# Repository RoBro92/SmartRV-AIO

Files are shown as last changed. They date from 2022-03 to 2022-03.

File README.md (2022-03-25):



# SmartRV AIO
**A ESP32 based smart home control board for a Camper/RV**

All feature requests are tracked in the GitHub issue tracker. 
[Feature Requests](https://github.com/RoBro92/feature-requests/issues)

This AIO board is planned to be able to work standalone or as part of a connected smart home network within a camper or RV. It will be designed based on suggestions from the community. As technology advances many are looking to automate tasks in day to day life, your recreational vehicle should be no different. Many existing monitoring systems are generally either very dated, or not very smart. This board will facilitate an all in one monitoring and control hub. 

The module has been kept as compact as possible and allows for a direct connection to 12v or 24v vehicle systems. 

**If you want to support the development you can purchase this board as a DIY kit or assembled from my Ko-Fi Shop [SmartRV Shop](https://ko-fi.com/smartrv/shop)**

## **I have developed two seperate versions of this module**

[AIO1 is THT and is suitable for at home soldering](#aio1)

[AIO2 is SMD and is designed to be assembled by a PCB manufacturer](#aio2)

###AIO1

# **THT Version 0.1**
This is the pre production initial design files with planned features and initial designs.

# **Features**
- [x] - ESP32 Microcontroller
- [x] - Individually controlled relays
- [x] - Input buttons 
- [x] - Tank temperature inputs
- [x] - Tank level inputs
- [x] - Auxilliary temperature & humidity input
- [x] - Spotlights/LED control & dimming
- [x] - RJ45 Output to Nextion Display
- [x] - Relay 1&2 are 12v direct supply for low current device 

# **Upcoming Changes**

- [ ] - RS485 serial connection
- [ ] - Bluetooth App
- [ ] - Bluetooth connection to external modules(such as Water tank module)
- [ ] - House battery voltage
- [ ] - Main battery voltage
- [ ] - On board programming
- [ ] - MQTT integration
- [ ] - Diesel heater control 

# **Images**

<table>
  <tr>
    <td>Schematic</td>
     <td>PCB Layout</td>
  </tr>
  <tr>
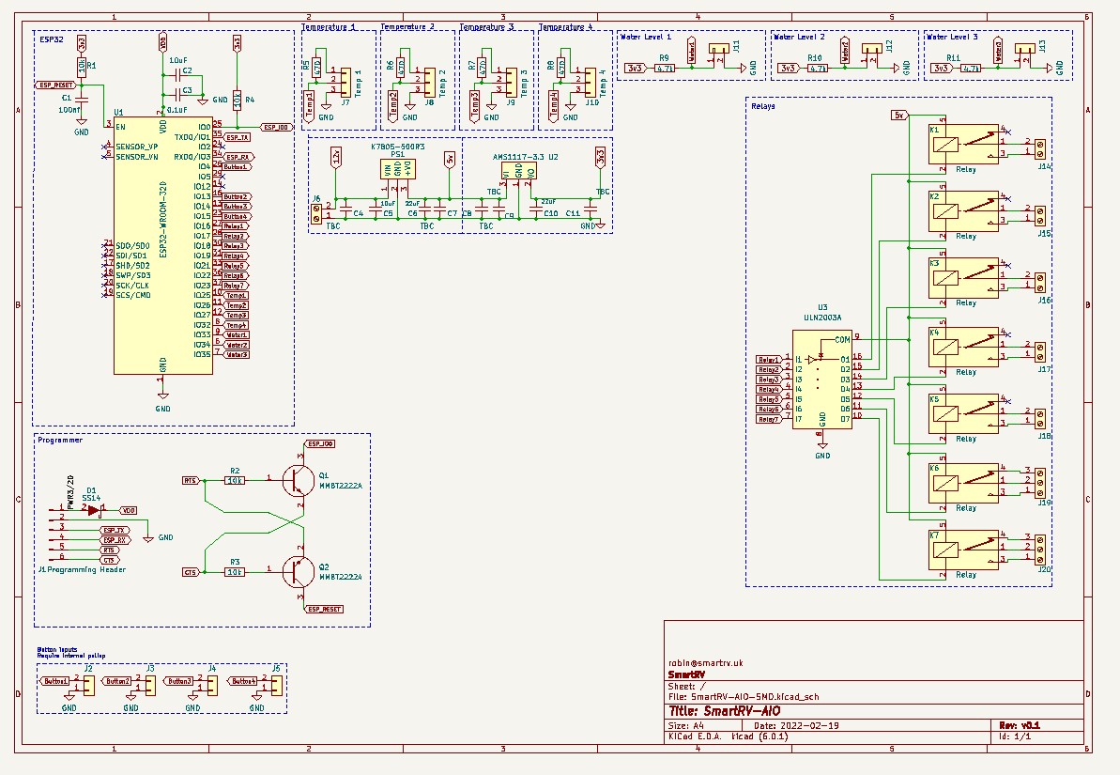
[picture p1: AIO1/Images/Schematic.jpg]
    <td></td>
    <td></td>
  </tr>
 </table>

# **WARNING**
This board does not have any fuse protection as such this must be provided externally.

###AIO2

# **SMD Version 0.1**
This is the pre production SMD initial design files with planned features and initial designs.

# **Features**
- [x] - ESP32 Microcontroller
- [x] - Individually controlled relays
- [x] - Input buttons 
- [x] - Tank temperature inputs
- [x] - Tank level inputs
- [x] - Auxilliary temperature & humidity input

# **Upcoming Changes**

- [ ] - RS485 serial connection
- [ ] - Bluetooth App
- [ ] - Bluetooth connection to external modules(such as Water tank module)
- [ ] - House battery voltage
- [ ] - Main battery voltage
- [ ] - On board programming
- [ ] - MQTT integration
- [ ] - Diesel heater control 
- [ ] - RJ45 Output to Nextion Display
- [ ] - Spotlights/LED control & dimming
- [ ] - Relay 1&2 are 12v direct supply for low current device 

# **Images**

<table>
  <tr>
    <td>Schematic</td>
     <td>PCB Layout</td>
  </tr>
  <tr>
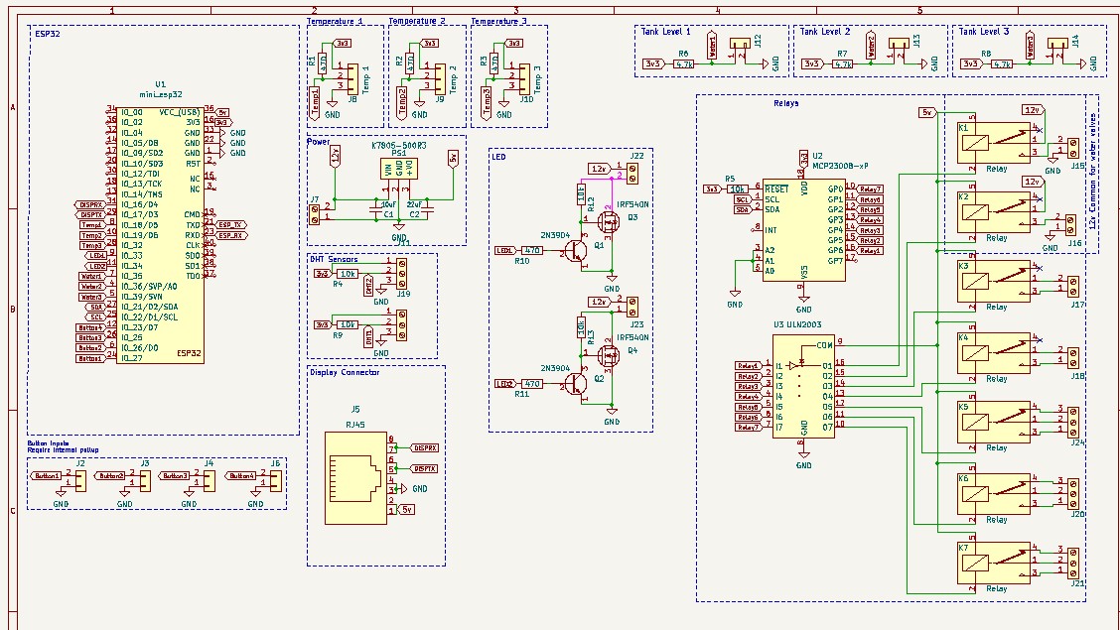
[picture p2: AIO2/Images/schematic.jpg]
    <td></td>
    <td></td>
  </tr>
 </table>

# **WARNING**
This board does not have any fuse protection as such this must be provided externally.

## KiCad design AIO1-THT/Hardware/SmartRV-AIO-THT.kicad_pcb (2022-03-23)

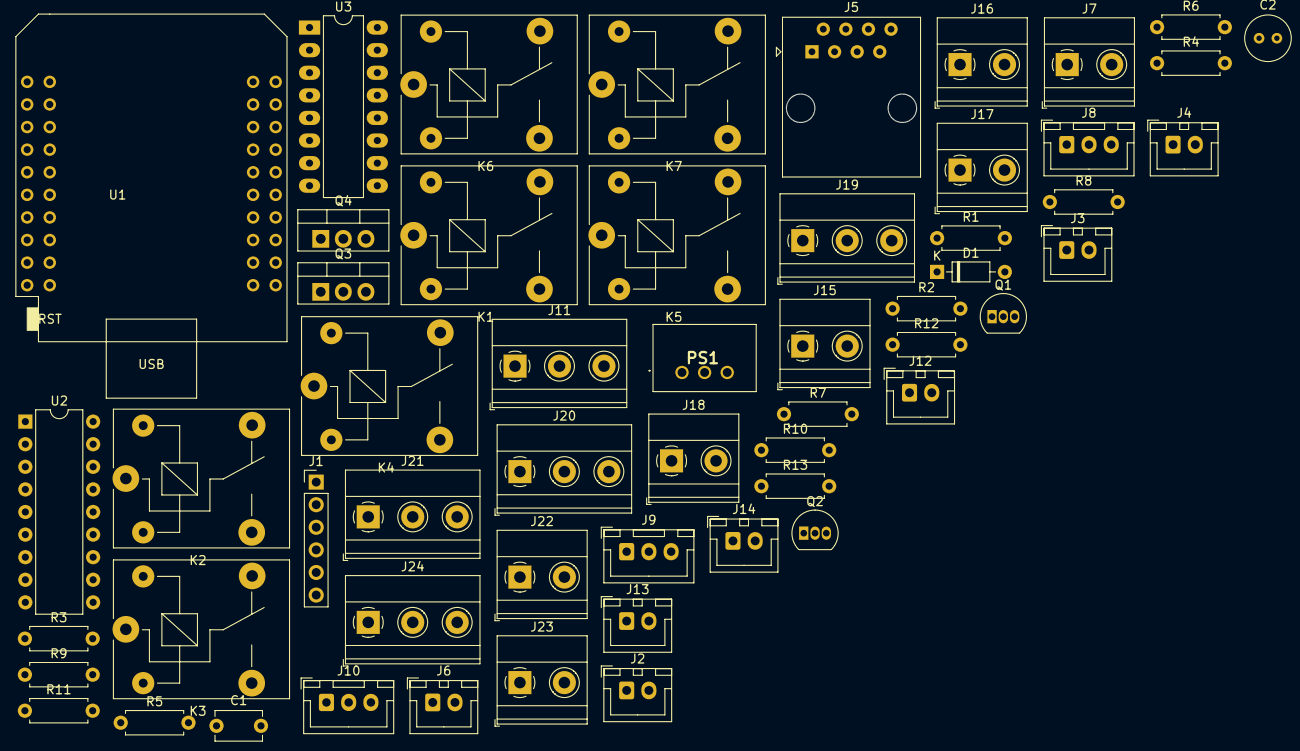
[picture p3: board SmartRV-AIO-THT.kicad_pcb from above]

Board: 2 copper layers, 55 parts (0 on the bottom side), 57 nets, no tracks yet.

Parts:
C1: 10uF; C_Disc_D5.1mm_W3.2mm_P5.00mm
C2: 22uF; C_Radial_D5.0mm_H5.0mm_P2.00mm
D1: 1N4148; D_DO-35_SOD27_P7.62mm_Horizontal
J1: Programming Header; PinHeader_1x06_P2.54mm_Vertical
J2: Button1; JST_XH_B2B-XH-A_1x02_P2.50mm_Vertical
J3: Button2; JST_XH_B2B-XH-A_1x02_P2.50mm_Vertical
J4: Button3; JST_XH_B2B-XH-A_1x02_P2.50mm_Vertical
J5: RJ45; RJ45_Amphenol_54602-x08_Horizontal
J6: Button4; JST_XH_B2B-XH-A_1x02_P2.50mm_Vertical
J7, J15, J16, J17, J18, J22, J23: Screw_Terminal_01x02; TerminalBlock_Phoenix_MKDS-1,5-2_1x02_P5.00mm_Horizontal
J8: Temp 1; JST_XH_B3B-XH-A_1x03_P2.50mm_Vertical
J9: Temp 2; JST_XH_B3B-XH-A_1x03_P2.50mm_Vertical
J10: Temp 3; JST_XH_B3B-XH-A_1x03_P2.50mm_Vertical
J11, J19, J20, J21, J24: Screw_Terminal_01x03; TerminalBlock_Phoenix_MKDS-1,5-3_1x03_P5.00mm_Horizontal
J12, J13, J14: Water Level Sensor; JST_XH_B2B-XH-A_1x02_P2.50mm_Vertical
K1, K2, K3, K4, K5, K6, K7: Relay; Relay_SPDT_SANYOU_SRD_Series_Form_C
PS1: K7805-500R3; K7805500R3
Q1, Q2: 2N3904; TO-92_Inline
Q3, Q4: IRF540N; TO-220-3_Vertical
R1, R2, R3: 470; R_Axial_DIN0207_L6.3mm_D2.5mm_P7.62mm_Horizontal
R4, R5, R9, R10, R11, R12, R13: 10k; R_Axial_DIN0207_L6.3mm_D2.5mm_P7.62mm_Horizontal
R6, R7, R8: 4.7k; R_Axial_DIN0207_L6.3mm_D2.5mm_P7.62mm_Horizontal
U1: mini_esp32; ESP32_mini
U2: MCP23008-xP; DIP-18_W7.62mm
U3: ULN2003; DIP-16_W7.62mm_LongPads

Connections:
3v3: J8.1, J9.1, J10.1, J11.1, J19.1, R1.1, R2.1, R3.1, R4.1, R5.1, R6.1, R7.1, R8.1, R9.1, U1.16 (3V3), U2.18 (VDD)
5v: C2.1, J5.1, J5.2, K1.5, K2.5, K3.5, K4.5, K5.5, K6.5, K7.5, PS1.3 (+VO), U1.35 (VCC_(USB)), U3.9 (COM)
12v: C1.1, J7.2, J22.1, J23.2, PS1.1 (VIN)
/PWR3/20: D1.2 (A), J1.1
DHT1: J19.2, R9.2
DHT2: J11.2, R4.2
DISPRX: J5.7, J5.8, U1.31 (IO_16/D4)
DISPTX: J5.5, J5.6, U1.29 (IO_17/D3)
ESP_RX: J1.4, U1.23 (RXD)
ESP_TX: J1.3, U1.21 (TXD)
GND: C1.2, C2.2, J1.2, J2.1, J3.1, J4.1, J5.3, J5.4, J6.1, J7.1, J8.3, J9.3, J10.3, J11.3, J12.2, J13.2, J14.2, J19.3, PS1.2 (GND), Q1.1 (E), Q2.1 (E), Q3.3 (S), Q4.3 (S), U1.1 (GND), U1.22 (GND), U1.33 (GND), U2.3 (A2), U2.4 (A1), U2.5 (A0), U2.9 (VSS), U3.8 (GND)
unnamed: J15.1, K1.3
unnamed: J15.2, K1.1
unnamed: J16.1, K2.3
unnamed: J16.2, K2.1
unnamed: J17.1, K3.3
unnamed: J17.2, K3.1
unnamed: J18.1, K4.3
unnamed: J18.2, K4.1
unnamed: J20.1, K6.3
unnamed: J20.2, K6.1
unnamed: J20.3, K6.4
unnamed: J21.1, K7.3
unnamed: J21.2, K7.1
unnamed: J21.3, K7.4
unnamed: K1.2, U3.16 (O1)
unnamed: K2.2, U3.15 (O2)
unnamed: K3.2, U3.14 (O3)
unnamed: K4.2, U3.13 (O4)
unnamed: J24.2, K5.1
unnamed: K5.2, U3.12 (O5)
unnamed: J24.1, K5.3
unnamed: J24.3, K5.4
unnamed: K6.2, U3.11 (O6)
unnamed: K7.2, U3.10 (O7)
unnamed: Q1.2 (B), R10.2
unnamed: Q1.3 (C), Q3.1 (G), R12.1
unnamed: Q2.2 (B), R11.2
unnamed: Q2.3 (C), Q4.1 (G), R13.1
unnamed: J22.2, Q3.2 (D), R12.2
unnamed: J23.1, Q4.2 (D), R13.2
unnamed: R5.2, U2.6 (~RESET)
Relay1: U2.16 (GP6), U3.1 (I1)
Relay2: U2.15 (GP5), U3.2 (I2)
Relay3: U2.14 (GP4), U3.3 (I3)
Relay4: U2.13 (GP3), U3.4 (I4)
Relay5: U2.12 (GP2), U3.5 (I5)
Relay6: U2.11 (GP1), U3.6 (I6)
Relay7: U2.10 (GP0), U3.7 (I7)
SCL: U1.25 (IO_22/D1/SCL), U2.1 (SCL)
SDA: U1.27 (IO_21/D2/SDA), U2.2 (SDA)
Temp1: J8.2, R1.2
Temp2: J9.2, R2.2
Temp3: J10.2, R3.2
Water1: J12.1, R6.2
Water2: J13.1, R7.2
Water3: J14.1, R8.2

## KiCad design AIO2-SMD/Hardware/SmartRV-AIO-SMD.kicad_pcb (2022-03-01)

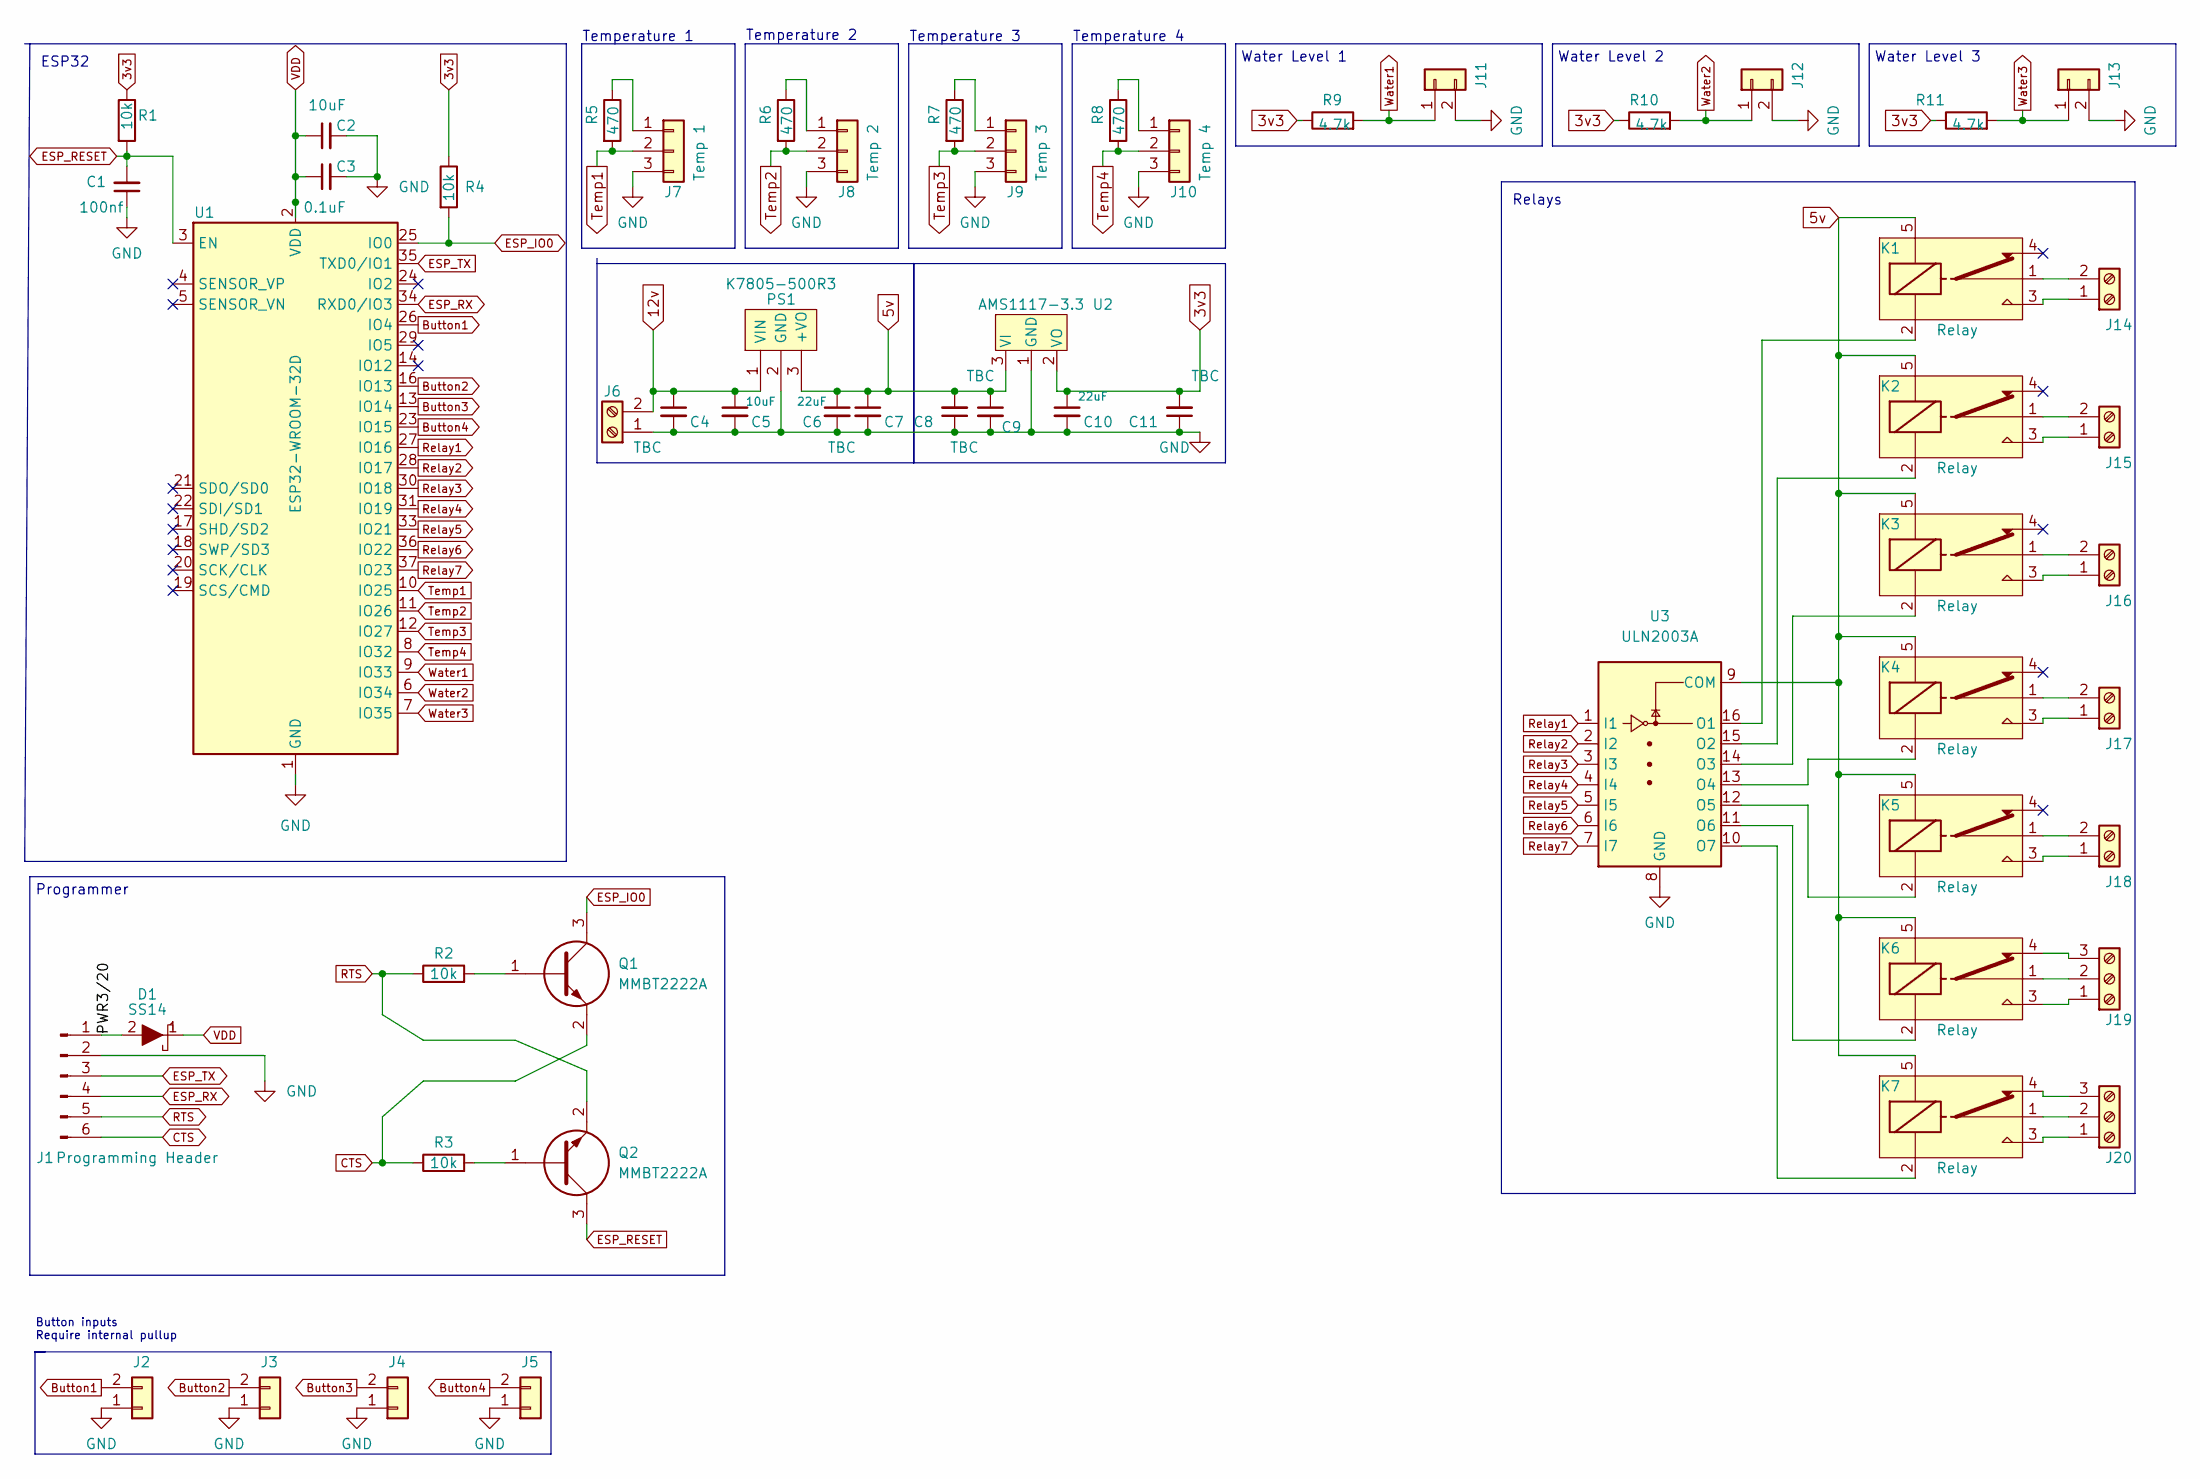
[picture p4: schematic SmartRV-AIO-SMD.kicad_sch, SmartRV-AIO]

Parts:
C1: 100nf; C_0805_2012Metric
C2, C5: 10uF; C_0805_2012Metric
C3: 0.1uF; C_0805_2012Metric
C4, C7, C8, C9, C11: TBC; C_0805_2012Metric
C6, C10: 22uF; C_0805_2012Metric
D1: SS14; DIOM5126X250N; Manufacturer_Part_Number SS14; Mouser Part Number 821-SS14
J1: Programming Header; PinHeader_1x06_P2.54mm_Vertical
J2: Button1; JST_XH_B2B-XH-A_1x02_P2.50mm_Vertical
J3: Button2; JST_XH_B2B-XH-A_1x02_P2.50mm_Vertical
J4: Button3; JST_XH_B2B-XH-A_1x02_P2.50mm_Vertical
J5: Button4; JST_XH_B2B-XH-A_1x02_P2.50mm_Vertical
J6, J14, J15, J16, J17, J18: Screw_Terminal_01x02; TerminalBlock_Phoenix_MKDS-1,5-2_1x02_P5.00mm_Horizontal
J7: Temp 1; JST_XH_B3B-XH-A_1x03_P2.50mm_Vertical
J8: Temp 2; JST_XH_B3B-XH-A_1x03_P2.50mm_Vertical
J9: Temp 3; JST_XH_B3B-XH-A_1x03_P2.50mm_Vertical
J10: Temp 4; JST_XH_B3B-XH-A_1x03_P2.50mm_Vertical
J11, J12, J13: Water Level Sensor; JST_XH_B2B-XH-A_1x02_P2.50mm_Vertical
J19, J20: Screw_Terminal_01x03; TerminalBlock_Phoenix_MKDS-1,5-3_1x03_P5.00mm_Horizontal
K1, K2, K3, K4, K5, K6, K7: Relay; Relay_SPDT_SANYOU_SRD_Series_Form_C
PS1: K7805-500R3; K7805500R3; Manufacturer_Part_Number K7805-500R3
Q1, Q2: MMBT2222A; SOT95P240X120-3N; Manufacturer_Part_Number MMBT2222A; Mouser Part Number 512-MMBT2222A
R1, R2, R3, R4: 10k; R_0805_2012Metric
R5, R6, R7, R8: 470; R_0805_2012Metric
R9, R10, R11: 4.7k; R_0805_2012Metric
U1: ESP32-WROOM-32D; ESP32-WROOM-32
U2: AMS1117-3.3; SOT-223-3_TabPin2
U3: ULN2003A; SOIC127P600X175-16N

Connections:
3v3: C10.1, C11.2, R1.1, R4.1, R9.1, R10.1, R11.1, U2.2 (VO)
5v: C6.1, C7.1, C8.2, C9.1, K1.5, K2.5, K3.5, K4.5, K5.5, K6.5, K7.5, PS1.3 (+VO), U2.3 (VI), U3.9 (COM)
12v: C4.1, C5.1, J6.2, PS1.1 (VIN)
/PWR3/20: D1.2, J1.1
Button1: J2.2, U1.26 (IO4)
Button2: J3.2, U1.16 (IO13)
Button3: J4.2, U1.13 (IO14)
Button4: J5.2, U1.23 (IO15)
CTS: J1.6, Q1.2, R3.1
ESP_IO0: Q1.3, R4.2, U1.25 (IO0)
ESP_RESET: C1.2, Q2.3, R1.2, U1.3 (EN)
ESP_RX: J1.4, U1.34 (RXD0/IO3)
ESP_TX: J1.3, U1.35 (TXD0/IO1)
GND: C1.1, C2.2, C3.2, C4.2, C5.2, C6.2, C7.2, C8.1, C9.2, C10.2, C11.1, J1.2, J2.1, J3.1, J4.1, J5.1, J6.1, J7.3, J8.3, J9.3, J10.3, J11.2, J12.2, J13.2, PS1.2 (GND), U1.1 (GND), U1.15 (GND), U1.38 (GND), U1.39 (GND), U2.1 (GND), U3.8 (GND)
unnamed: J7.1, R5.1
unnamed: J8.1, R6.1
unnamed: J9.1, R7.1
unnamed: J10.1, R8.1
unnamed: J14.1, K1.3
unnamed: J14.2, K1.1
unnamed: J15.1, K2.3
unnamed: J15.2, K2.1
unnamed: J16.1, K3.3
unnamed: J16.2, K3.1
unnamed: J17.1, K4.3
unnamed: J17.2, K4.1
unnamed: J18.1, K5.3
unnamed: J18.2, K5.1
unnamed: J19.1, K6.3
unnamed: J19.2, K6.1
unnamed: J19.3, K6.4
unnamed: J20.1, K7.3
unnamed: J20.2, K7.1
unnamed: J20.3, K7.4
unnamed: K1.2, U3.16 (O1)
unnamed: K2.2, U3.15 (O2)
unnamed: K3.2, U3.14 (O3)
unnamed: K4.2, U3.13 (O4)
unnamed: K5.2, U3.12 (O5)
unnamed: K6.2, U3.11 (O6)
unnamed: K7.2, U3.10 (O7)
unnamed: Q1.1, R2.2
unnamed: Q2.1, R3.2
RTS: J1.5, Q2.2, R2.1
Relay1: U1.27 (IO16), U3.1 (I1)
Relay2: U1.28 (IO17), U3.2 (I2)
Relay3: U1.30 (IO18), U3.3 (I3)
Relay4: U1.31 (IO19), U3.4 (I4)
Relay5: U1.33 (IO21), U3.5 (I5)
Relay6: U1.36 (IO22), U3.6 (I6)
Relay7: U1.37 (IO23), U3.7 (I7)
Temp1: J7.2, R5.2, U1.10 (IO25)
Temp2: J8.2, R6.2, U1.11 (IO26)
Temp3: J9.2, R7.2, U1.12 (IO27)
Temp4: J10.2, R8.2, U1.8 (IO32)
VDD: C2.1, C3.1, D1.1, U1.2 (VDD)
Water1: J11.1, R9.2, U1.9 (IO33)
Water2: J12.1, R10.2, U1.6 (IO34)
Water3: J13.1, R11.2, U1.7 (IO35)

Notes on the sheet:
Relays
Temperature 4
ESP32
Temperature 1
Temperature 2
Temperature 3
Button inputs Require internal pullup
Programmer
Water Level 2
Water Level 3
Water Level 1

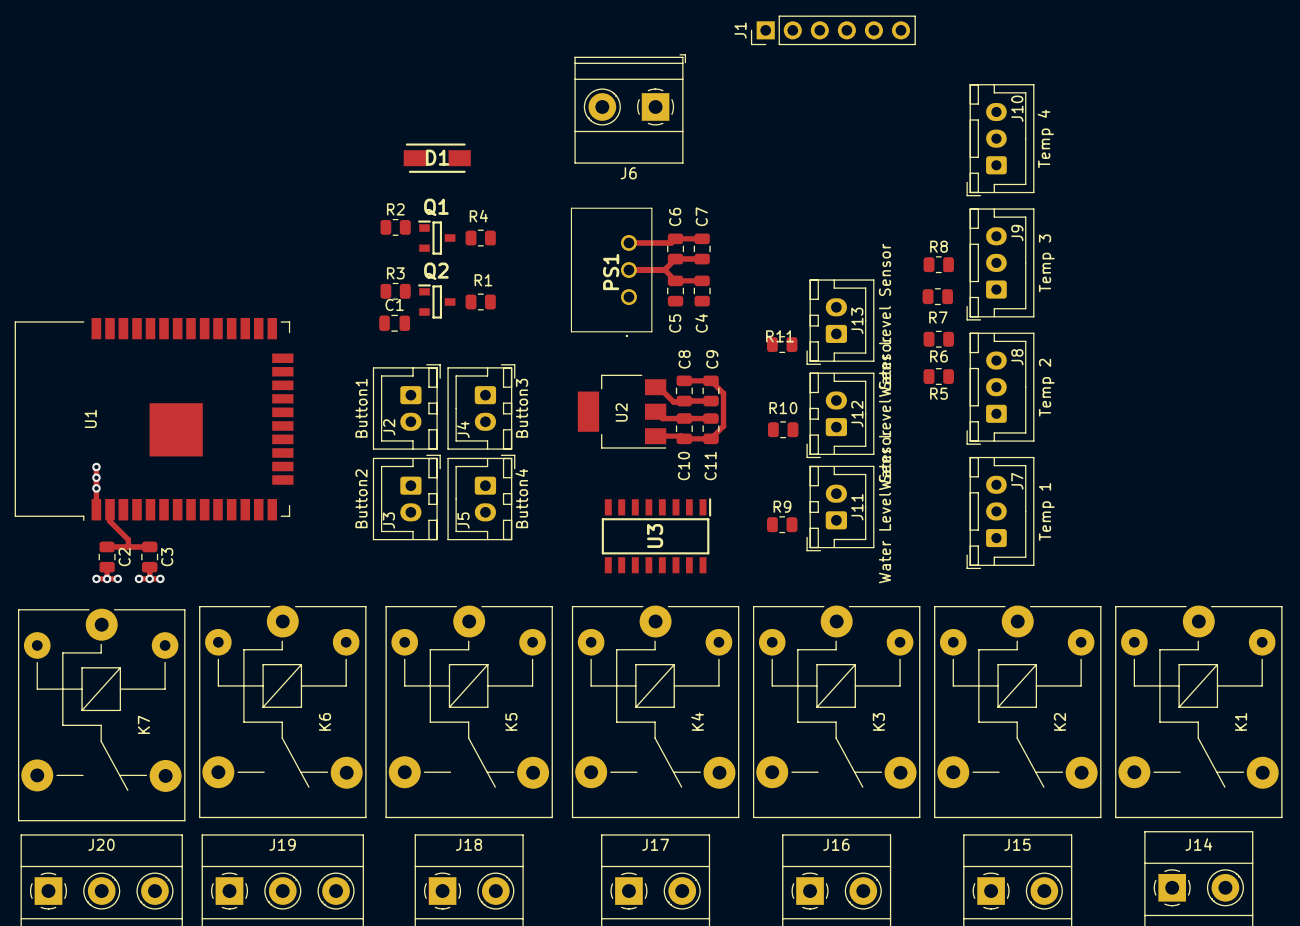
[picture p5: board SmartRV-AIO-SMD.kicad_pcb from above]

Board: 2 copper layers, 56 parts (0 on the bottom side), 59 nets.

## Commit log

2022-03-01 Added Kicad schematic and PCB files
    [SmartRV-AIO.kicad_pcb, SmartRV-AIO.kicad_sch]
2022-03-23 updated schematic and images
    [SmartRV-AIO-THT.kicad_pcb, SmartRV-AIO-THT.kicad_sch, SmartRV-AIO.kicad_pcb]
2022-03-25 Added images for SMD schematic and updated main readme
2022-03-25 Resotre files from backup
    [SmartRV-AIO-THT.kicad_pcb, SmartRV-AIO-THT.kicad_sch]
2022-03-25 updated filenames
    [SmartRV-AIO-SMD.kicad_pcb, SmartRV-AIO-SMD.kicad_sch, SmartRV-AIO-THT.kicad_pcb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]
